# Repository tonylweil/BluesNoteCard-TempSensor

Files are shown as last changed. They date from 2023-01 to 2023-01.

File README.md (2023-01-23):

# BluesNoteCard-TempSensor

This device is used to monitor a vacant house during a vacation. It reports temperature, humidity, mains power and battery life over cellular. There is an OLED screen to display info only while on USB power.The box runs on USB power unless there is a power outage. Data is uploaded to the free version of Ubidots. Daily reports and important events (low temp, power outage, etc) are sent to text messages and email.

A custom hat/shield contains all the extra components and plugs into the headers on the Notecard. See Schematic.
Components:

* Blues Notecard-F & antenna
* ESP32-Feather
* Htu31d Temp and Humidity I2C Sensor (www.adafruit.com/product/5580)
* 1200mAh Lipo battery
* MAX17048 Lipo Fuel Gauge (www.adafruit.com/product/4832)
* I2C OLED
* DPDT power switch
* 3D Printed enclosure

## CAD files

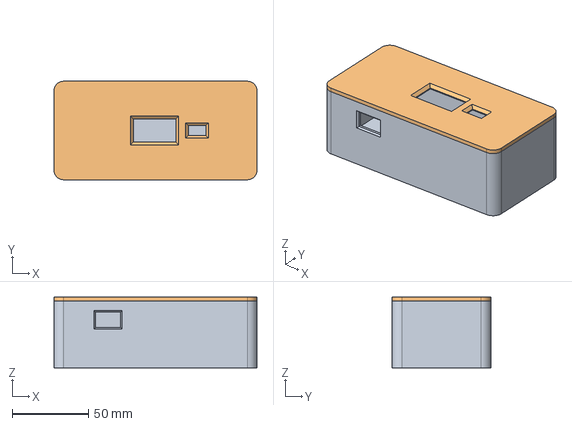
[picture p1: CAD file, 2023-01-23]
NotecardBox.FCStd
133.3 x 64.8 x 46.4 mm
Lid

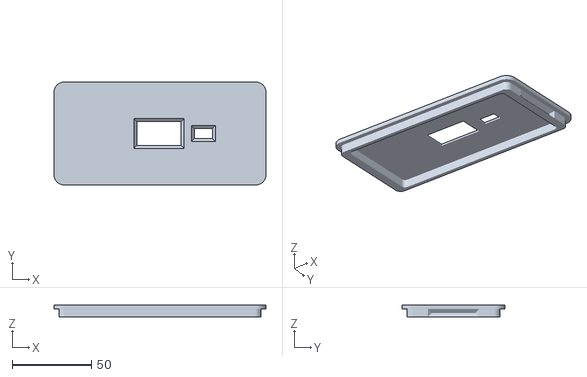
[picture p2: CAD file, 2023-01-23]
NotecardBox-Lid.020.stl
133.4 x 64.8 x 7.62

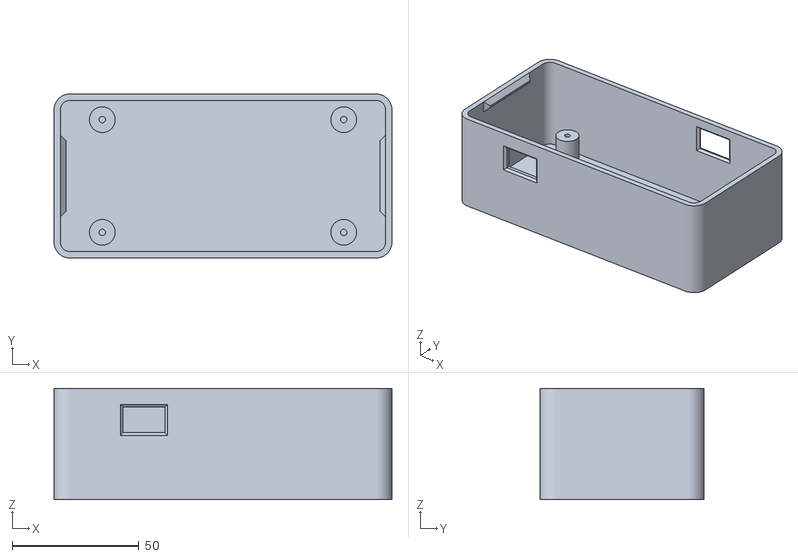
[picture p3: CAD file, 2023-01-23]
NotecardBox-Box.stl
133.4 x 64.8 x 43.8

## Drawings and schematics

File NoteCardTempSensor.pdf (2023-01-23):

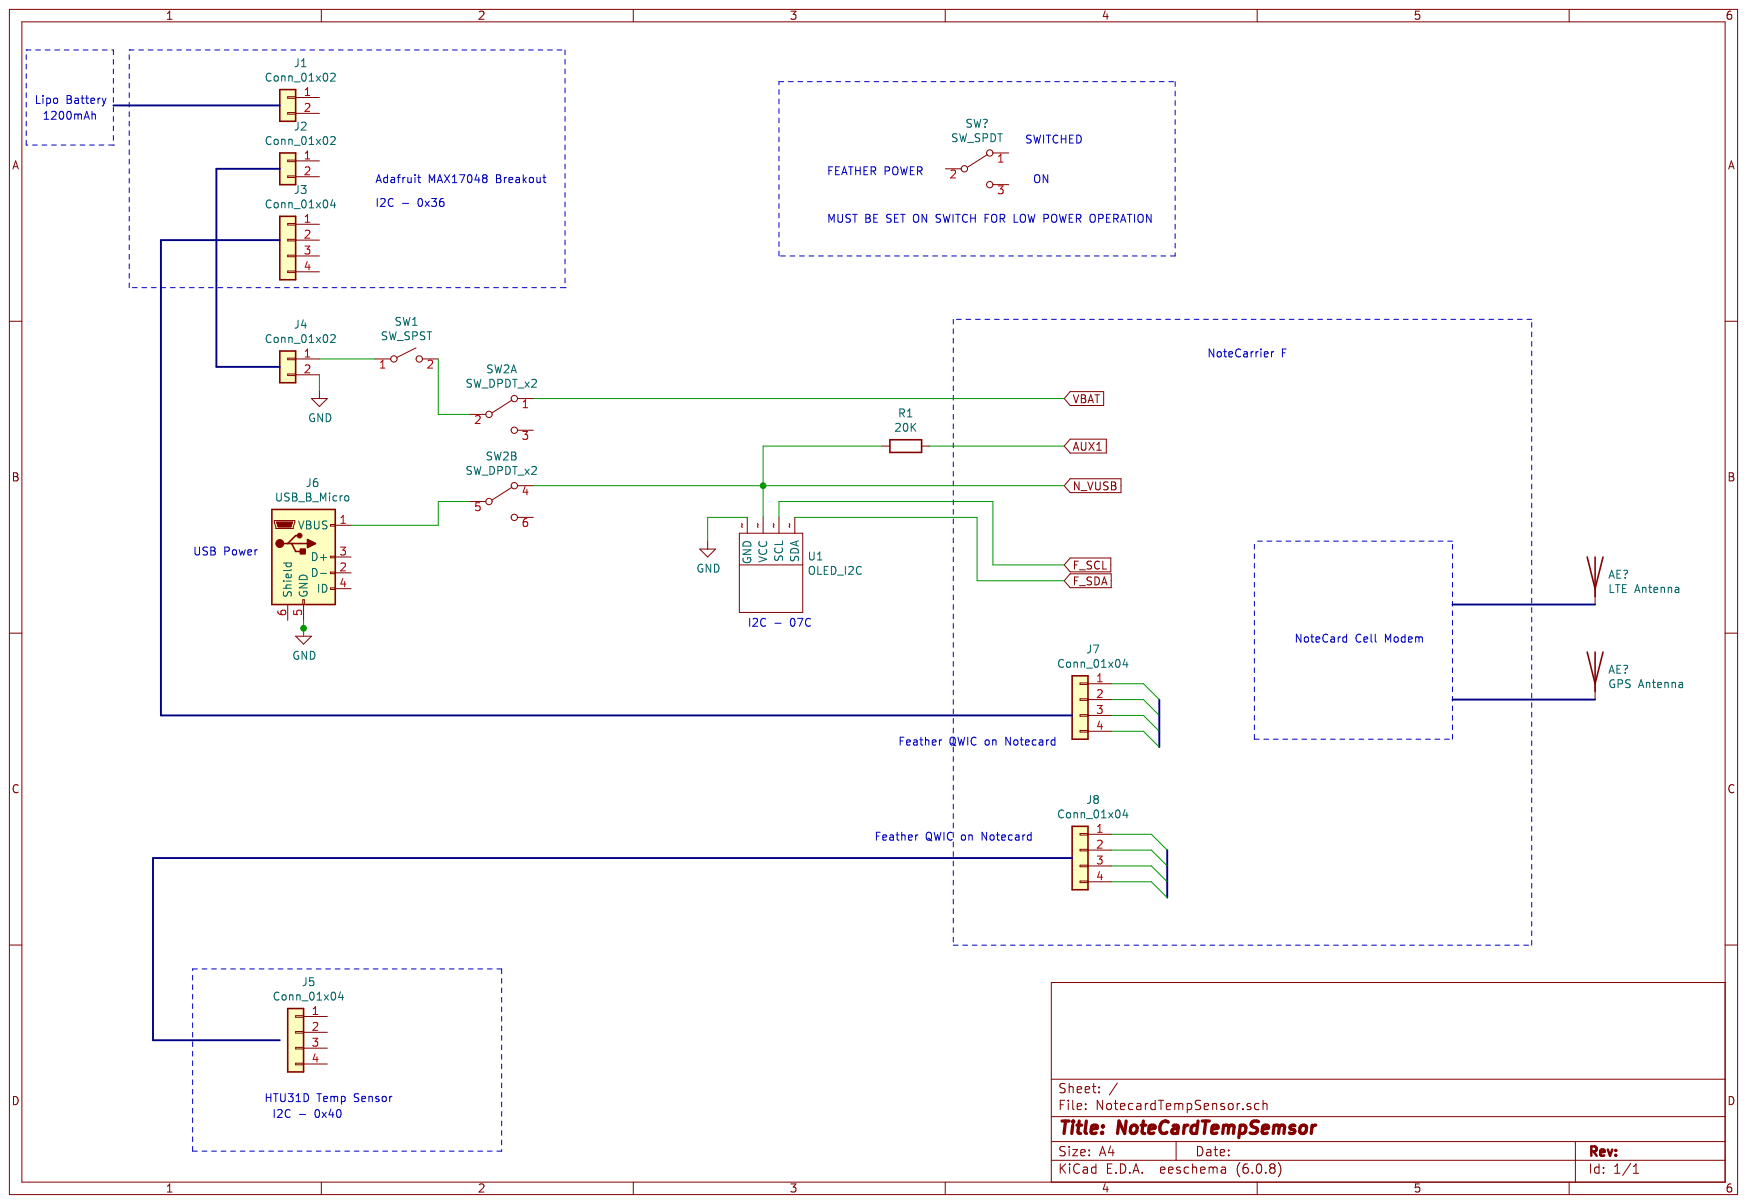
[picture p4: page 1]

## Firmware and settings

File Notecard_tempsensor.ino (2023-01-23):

// Notecard with HTU31-D Temp/Humidity sensor
// output to serial monitor

/*
 * Sleepy Sensor Application
 *
 * The goal of this application is to show the elements required to construct an
 * application which leverages the capabilities of the Notecard to minimize
 * battery consumption by controlling the wake time of the host MCU.
 *
 * Use the following diagram to wire up the circuit. Note the Notecard's `ATTN`
 * pin (exposed via the Notecarrier) is wired to the enable pin of the host MCU.
 *  ________________________________________
 * |  ____________________________________  |               ____________________
 * | |                                    | |              /
 * | |        _________________           | |             |  O
 * | |       |O|             |O|          | |             |     (Notecarrier-AL)
 * | --> SDA-|*  ___________  *|-21       | |       VUSB>-|[]
 * ----> SCL-|* | ESPRESSIF | *|-TX       | |  ----> BAT>-|[]
 *        14-|* |ESP32-WROOM| *|-RX       | |  |    MAIN>-|[]
 *        32-|* |CE         | *|-MI       | |  |     VIO>-|[]
 *        15-|* |           | *|-MO       | |  |          |[]
 *        33-|* |       ___ | *|-SCK      | |  |       V+-|[]
 *        27-|* |      |   || *|-A5    ---^-^--^----> GND-|[]
 *        12-|* |______|___|| *|-A4    |  | |  |       EN-|[]
 *        13-|*               *|-A3    |  | |  |      RST-|[]
 *       USB-|*               *|-A2    |  | |  |          |[]
 * -----> EN-|*         ----- *|-A1    |  | ---^----> SCL-|[]
 * | --> BAT-|*___      |   | *|-A0    |  -----^----> SDA-|[]
 * | |       |    |     ----- *|-GND <--       | --> ATTN-|[]
 * | |       |    |        _  *|-NC            | |  AUXEN-|[]
 * | |       |-----       |O| *|-3V            | |  AUXRX-|[]
 * | |       |      -----     *|-RST           | |  AUXTX-|[]
 * | |       |O___0_|___|_0___O|               | |   AUX1-|[]
 * | |                                         | |   AUX2-|[]
 * | |_________________________________________| |   AUX3-|[]
 * |_____________________________________________|   AUX4-|[]
 *                                                     RX-|[]
 *                                                     TX-|[]
 *                                                        |
 *                                                        |  O
 *                                                         \____________________
 *
 * NOTE: This sample is intended to compile for any Arduino compatible MCU
 * architecture and Notecard/Notecarrier combination. However, it was created
 * and tested using the Adafruit Huzzah32 and Notecarrier-AL.
 *
 * NOTE: This example has intentionally omitted error checking in order to
 * highlight the elements required to make a power-efficient application.
 */

//=================IMPORTANT: MUST WIRE Notecarrier ATTN pin to F_EN pin as in above drawing==============

// Notecard
#include <Notecard.h>
#define usbSerial Serial
#define productUID "com.xxxxxxxxxxx:tempsensor"
Notecard notecard;
// This period controls the waking frequency of your host MCU, and will have a
// direct impact on battery conservation. It should be used to strike a balance
// between battery performance and data collection requirements.
//static const size_t PERIOD_S = 1800; // 30 min
static const size_t PERIOD_S = 900; // 900 seconds = 15 min updates

#include <Wire.h>
#include "Adafruit_HTU31D.h"
Adafruit_HTU31D htu = Adafruit_HTU31D();

#include "Adafruit_MAX1704X.h"
Adafruit_MAX17048 maxlipo;

int powerPin = 14; //feather GPIO14, Note F_D5, Orange
int powerValue = 0;

#include <Adafruit_GFX.h>
#include <Adafruit_SSD1306.h>

#define SCREEN_WIDTH 128 // OLED display width, in pixels
#define SCREEN_HEIGHT 64 // OLED display height, in pixels

//#define OLED_RESET     -1 // Reset pin # (or -1 if sharing Arduino reset pin)
#define SCREEN_ADDRESS 0x3C ///< See datasheet for Address; 0x3D for 128x64, 0x3C for 128x32
Adafruit_SSD1306 display(SCREEN_WIDTH, SCREEN_HEIGHT, &Wire);
//Adafruit_SSD1306 display(128, 64, &Wire);

float batteryValue = 0;

void setup() {
  usbSerial.begin(115200);
  usbSerial.println();
  usbSerial.println("==============================================================================");
  usbSerial.println("Version: Notecard_tempsensor_htu31d_power_batt-7_ATTN_OLED_USB_MAX_FINAL_AUX");
  usbSerial.println("==============================================================================");
  usbSerial.println();

  // Initialize Display
  // SSD1306_SWITCHCAPVCC = generate display voltage from 3.3V internally
  display.begin(SSD1306_SWITCHCAPVCC, SCREEN_ADDRESS); 
  // Initialize Max 17048 Lipo Fuel Gauge
  maxlipo.begin();
 // Initialize Notecard
  notecard.begin();
  notecard.setDebugOutputStream(usbSerial);
//initialize temp sensor
  htu.begin(0x40);  

 // Provide visual signal when the Host MCU is powered
  pinMode(LED_BUILTIN, OUTPUT);
  digitalWrite(LED_BUILTIN, HIGH); 

  pinMode(powerPin, INPUT_PULLDOWN); // Power Sense pin - HIGH if USB power is on , 5V, no divider!

  // Configure Notecard to synchronize with Notehub periodically, as well as
  // adjust the frequency based on the battery level 
 {
 J * req = notecard.newRequest("hub.set");
 JAddStringToObject(req, "product", productUID);
 JAddStringToObject(req, "mode", "periodic");
 JAddStringToObject(req, "voutbound", "usb:15;high:15;normal:15;low:60;dead:0"); 
 JAddStringToObject(req, "vinbound", "usb:15;high:15;normal:15;low:60;dead:0");
 //JAddStringToObject(req, "vinbound", "usb:60;high:60;normal:60;low:480;dead:0");
 notecard.sendRequest(req);
 }

 // Optimize voltage variable behaviors for LiPo battery
  {
    J * req = notecard.newRequest("card.voltage");
    JAddStringToObject(req, "mode", "lipo");
    notecard.sendRequest(req);
  }

  // Set up Notecarrier AUX GPIO for monitoring USB power connected to AUX1
 {
 J *req = NoteNewRequest("card.aux");
 JAddStringToObject(req, "mode", "gpio");
 J *pins = JAddArrayToObject(req, "usage");
 JAddItemToArray(pins, JCreateString("input-pulldown")); // AUX1
 JAddItemToArray(pins, JCreateString("off")); // AUX2
 JAddItemToArray(pins, JCreateString("off")); // AUX3
 JAddItemToArray(pins, JCreateString("off")); // AUX4
 JAddBoolToObject(req, "sync", true);
 JAddStringToObject(req, "file", "power-outage.qo"); // is this necessary or should it be sensors.qo?
 NoteRequest(req);
 }

 
  //ReadData();
  powerValue = digitalRead(powerPin); // 0=OFF, 1=ON // AC Power Sensor
  sensors_event_t humidity, temp;
  htu.getEvent(&humidity, &temp);// populate temp and humidity objects with fresh data

  batteryValue = maxlipo.cellPercent();
  if (batteryValue > 100) { 
    batteryValue = 100;
    }

//SendData();  //Send data to Notehub
  usbSerial.println("=======================");
  usbSerial.println("Sending data to Notehub");
  usbSerial.println("=======================");
    {
    J * req = notecard.newRequest("note.add");
    JAddStringToObject(req, "file", "sensors.qo");
    JAddBoolToObject(req, "sync", true);
    J * body = JAddObjectToObject(req, "body");
    if (body)
    {
      JAddNumberToObject(body, "temp", temp.temperature * 1.8 + 32);
      JAddNumberToObject(body, "humidity", humidity.relative_humidity);
      JAddNumberToObject(body, "battery",batteryValue);
      JAddNumberToObject(body, "power", powerValue);
    }
    notecard.sendRequest(req);
  } 
  if(powerValue == 1) {
   //DisplayData();
   display.clearDisplay();
   display.setCursor(0,0);
   display.setTextSize(2);             // Draw 2X-scale text
   display.setTextColor(SSD1306_WHITE);

   display.print(F("Temp:"));
   display.print((temp.temperature)* 1.8 + 32,0);
   display.println(F(" F"));
   display.print(F("Hum :"));
   display.print(humidity.relative_humidity,0);
   display.println(F(" %"));
   display.print(F("Batt:"));
   display.print(batteryValue,0);
   display.println(F(" %"));
   display.print(F("AC  :"));
    if(powerValue == 1) {
     display.println("ON");
    }
    else {
     display.println("OFF");
    }
   display.display();
  }
}

void loop() {
  // Request sleep from loop to safeguard against tranmission failure, and
  // ensure sleep request is honored so power usage is minimized.
    {
      // Create a "command" instead of a "request", because the host
      // MCU is going to power down and cannot receive a response.
      J * req = NoteNewCommand("card.attn");
      JAddStringToObject(req, "mode", "sleep");
      JAddNumberToObject(req, "seconds", PERIOD_S);
      notecard.sendRequest(req);
    }
  // Wait 1s before retrying
 delay(1000);
   
}
